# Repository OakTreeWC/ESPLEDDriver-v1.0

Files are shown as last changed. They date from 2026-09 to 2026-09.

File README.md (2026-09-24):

# ESPLEDDriver-v1.0 (In Progress)
ESPLEDDriver is an ESP Powered LED Driver Board for both Addressable and Non-Addressable LEDS. It features a ESP32-WROOM, with either a built in antenna or u.fl port, as well as 4 mosfet channels for powering monochrome and multicolor leds. 
All GPIO pins are exposed directly to the IO headers on the right side, and all power/led related IO can be found on the left side via the screw terminals.
Components have been sized accordingly to support 5-30V input, and up to 5 amps of current draw.



## Firmware
Due to the PD complexity of adding a USBC port to this project, I refrained from adding one. However, that does mean that programming the board requires using a USB to UART adapter.

In terms of firmware to be run on this, I will be using WLED, but ESPHome or any other ESP based software can be used to control it as well.

## Usage
This can be used in multiple ways, but what I believe is the most interesting (and fun) way to do it is to just integrate it with [Home Assistant](https://www.home-assistant.io/). If you really wanted to though, you could just use the Web Interface of WLED, or make your own firmware with its own API or something. The possibilities are literally endless, which is what makes the ESP platform so great.

## I/O
|Pin Number|Function|
|---|---|
|0|Addressable LED Data Line|
|4|Non-Addressable LED Channel 1/Red|
|5|Non-Addressable LED Channel 2/Green|
|6|Non-Addressable LED Channel 3/Blue|
|7|Non-Addressable LED Channel 4/White|

All other non-strapping pins are just free, so one may use them for any other purpose.

## Example Wiring Diagrams




## PCB



## Bill Of Materials
|Item |Description |Qty.|Unit Price (USD)|Total Price  (USD)|URL |Running Total (USD incl. tax)|
|---|---|----|---|---|---|---|
|ESP32-C3-WROOM-02U |ESP32 RF TXRX MOD BLUETOOTH U.FL SMD |1 |$3.71 |$3.71 |https://www.digikey.com/en/products/detail/espressif-systems/ESP32-C3-WROOM-02U-N4/15222540 |$3.71 |
|277-1580-ND |5POS Terminal Block, Side Entry, 5mm |1 |$1.28 |$1.28 |https://www.digikey.com/en/products/detail/phoenix-contact/1935190/568617 |$4.99 |
|277-1578-ND |3POS Terminal Block, Side Entry, 5mm |1 |$0.72 |$0.72 |https://www.digikey.com/en/products/detail/phoenix-contact/1935174/568615 |$5.71 |
|277-1667-ND |2POS Terminal Block, Side Entry, 5mm |1 |$0.53 |$0.53 |https://www.digikey.com/en/products/detail/phoenix-contact/1935161/568614 |$6.24 |
|IRLR2705PBFCT-ND |MOSFET N-CH 55V 28A DPAK |10  |$0.58 |$5.76 |https://www.digikey.com/en/products/detail/infineon-technologies/IRLR2705TRPBF/812649 |$12.00 |
|776-MAF95310-ND |185mm UFL Antenna |1 |$1.13 |$1.13 |https://www.digikey.com/en/products/detail/ezurio/MAF95310/5876486 |$13.13 |
|311-330HRCT-ND |RES 330 OHM 1% 1/10W 0603 |10  |$0.025 |$0.25 |https://www.digikey.com/en/products/detail/yageo/RC0603FR-07330RL/727162 |$13.38 |
|RNCP0603FTD10K0CT-ND |RES 10K OHM 1% 1/8W 0603 |10  |$0.01 |$0.12 |https://www.digikey.com/en/products/detail/stackpole-electronics-inc/RNCP0603FTD10K0/2240139 |$13.50 |
|5272-XL1509-3.3-EVCT-ND |XL1509 IC REG BUCK 3.3V 3A 8SOP |1 |$0.93 |$0.93 |https://www.digikey.com/en/products/detail/evvo/XL1509-3-3-EV/24370104 |$14.43 |
|4878-SK34SMA-3GCT-ND |DIODE SCHOTTKY 40V 3A SMA |1 |$0.35 |$0.35 |https://www.digikey.com/en/products/detail/diotec-semiconductor/SK34SMA-3G/13155211 |$14.78 |
|P16479CT-ND |CAP ALUM POLY 180UF 20% 16V SMD |1 |$1.55 |$1.55 |https://www.digikey.com/en/products/detail/panasonic-industry/16SVPF180M/4204811 |$16.33 |
|1276-1860-1-ND |CAP CER 1UF 50V X5R 0603 |10  |$0.08 |$0.80 |https://www.digikey.com/en/products/detail/samsung-electro-mechanics/CL10A105KB8NNNC/3887518 |$17.13 |
|36-3568-ND |FUSE HOLDER BLADE 500V 30A PCB |1 |$1.31 |$1.31 |https://www.digikey.com/en/products/detail/keystone-electronics/3568/2137306 |$18.44 |
|493-1111-ND |CAP ALUM 1000UF 20% 50V RADIAL |1 |$1.30 |$1.30 |https://www.digikey.com/en/products/detail/nichicon/UVR1H102MHD/588852 |$19.74 |
|SMBJ30ALFCT-ND |TVS DIODE 30VWM 48.4VC DO214AA |1 |$0.50 |$0.50 |https://www.digikey.com/en/products/detail/littelfuse-inc/SMBJ30A/286004 |$20.24 |
|SRR1210A-680MCT-ND |FIXED IND 68UH 3A 102 MOHM SMD |1 |$1.47 |$1.47 |https://www.digikey.com/en/products/detail/bourns-inc/SRR1210A-680M/5031009 |$21.71 |
|399-A768MS107M1HLAE024CT-ND|CAP ALUM POLY 100UF 20% 50V SMD |1 |$1.22 |$1.22 |https://www.digikey.com/en/products/detail/kemet/A768MS107M1HLAE024/12704540 |$22.93 |
|Female IO Headers |20PCS Single Row Straight Female Pin Socket Pin Header Connector Pin Strip 2.54mm Spacing for PCB Board Shield|1 |$5.99 |$5.99 |https://www.amazon.com/Ferwooh-Single-Straight-Connector-Spacing/dp/B0CZ6X313F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|$28.92 |
|450-1650-ND |SWITCH TACTILE SPST-NO 0.05A 24V |2 |$0.13 |$0.26 |https://www.digikey.com/en/products/detail/te-connectivity-alcoswitch-switches/1825910-6/1632536 |$29.18 |
|F989-ND |FUSE AUTOMOTIVE 5A 32VDC BLADE |2 |$0.39 |$0.78 |https://www.digikey.com/en/products/detail/littelfuse-inc/0297005-WXNV/146583 |$29.96 |
|Digikey Shipping | |1 |$4.99 |$4.99 | |$34.95 |
|Digikey Tariffs | |1 |$4.71 |$4.71 | |$39.66 |
|PCB |From JLCPCB |1 |$4.00 |$4.00 | |$43.66 |
|JLC Shipping | |1 |$6.77 |$6.77 | |$50.43 |
|Digikey TAX | |1 |$2.80 |$2.80 | |$53.23 |
|Amazon TAX | |1 |$0.63 |$0.63 | |$53.86 |

## AI Usage Declaration
AI was used in the making of this project, in component research, schematic/pcb verification, general sanity checks, as well as some copilot commit notes (for readme)

## Gallery




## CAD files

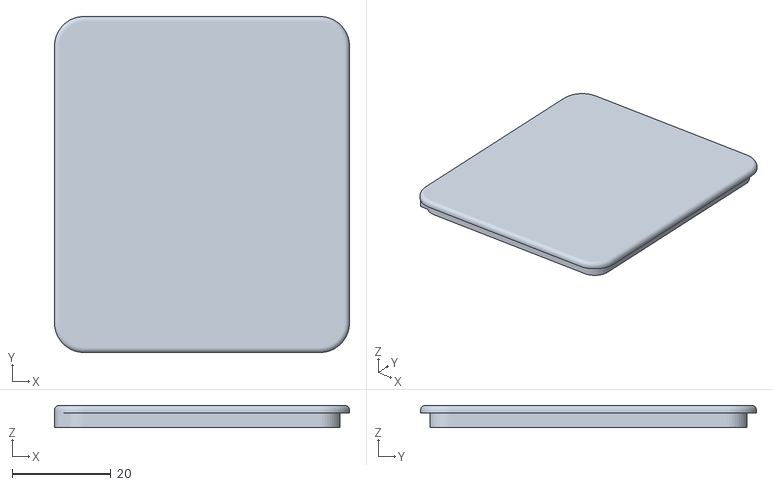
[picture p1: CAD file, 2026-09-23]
CAD/Upper Case.stl
59.6 x 67.9 x 4.50

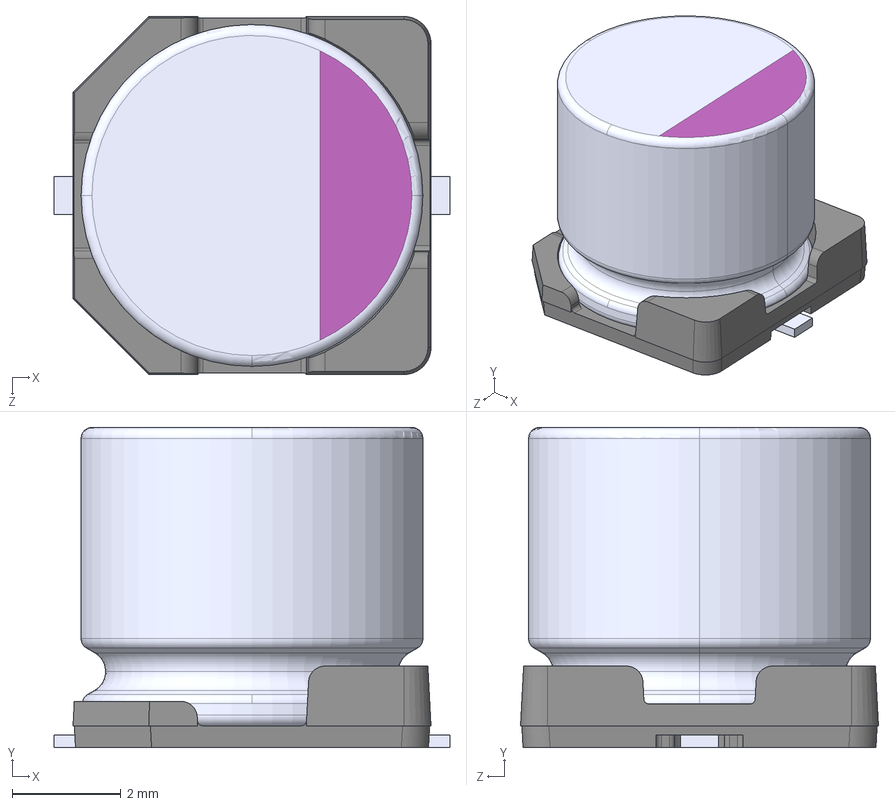
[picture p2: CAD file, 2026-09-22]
PCB/resources/16SVPF180M/16SVPF180M.step
7.30 x 5.90 x 6.60 mm

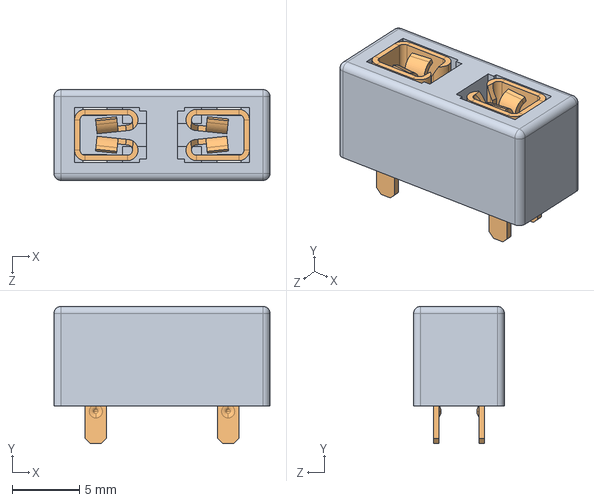
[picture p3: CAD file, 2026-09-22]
PCB/resources/3568/3568.step
16.0 x 10.2 x 6.73 mm
F3568-1
3557_rev.C x 2

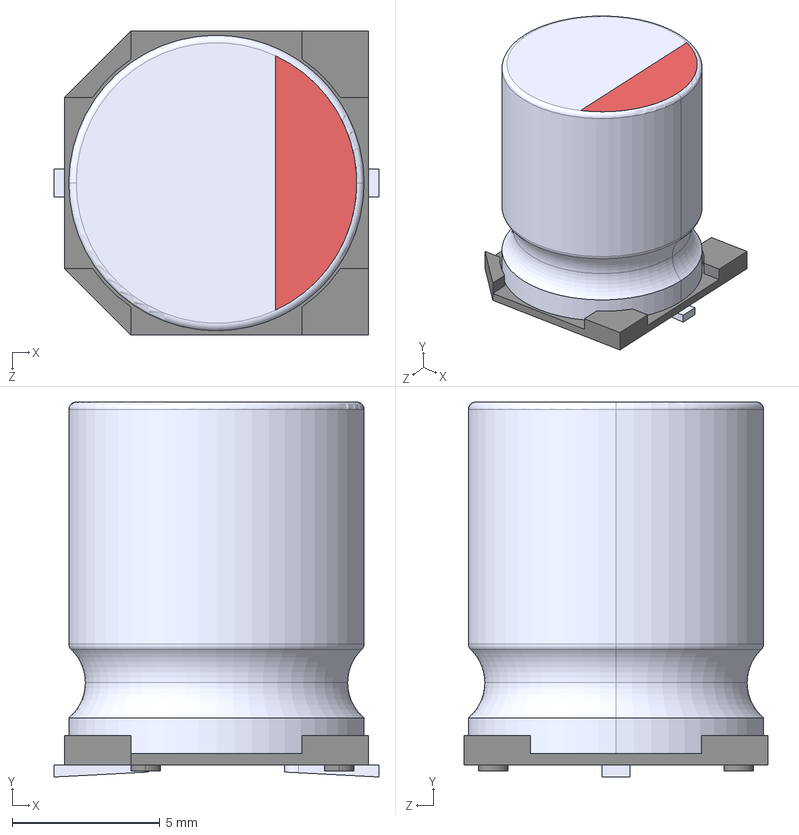
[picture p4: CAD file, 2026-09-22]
PCB/resources/A768MS107M1HLAE024/A768MS107M1HLAE024.step
11.0 x 12.7 x 10.3 mm

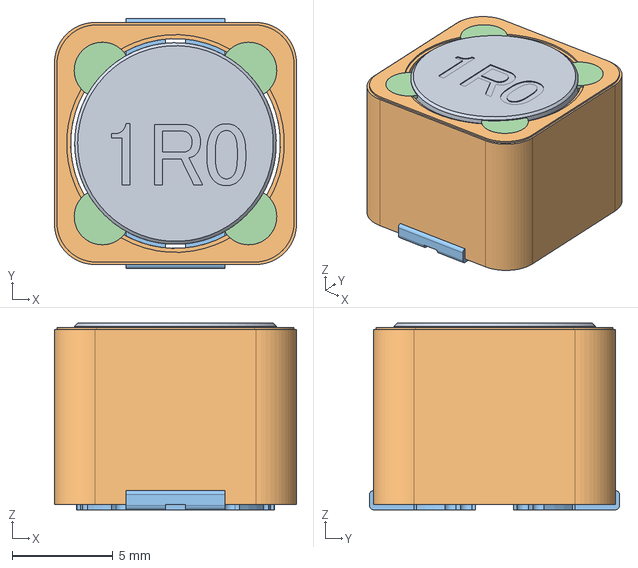
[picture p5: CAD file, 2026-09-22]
PCB/resources/SRR1210A.STP
12.0 x 12.4 x 9.25 mm

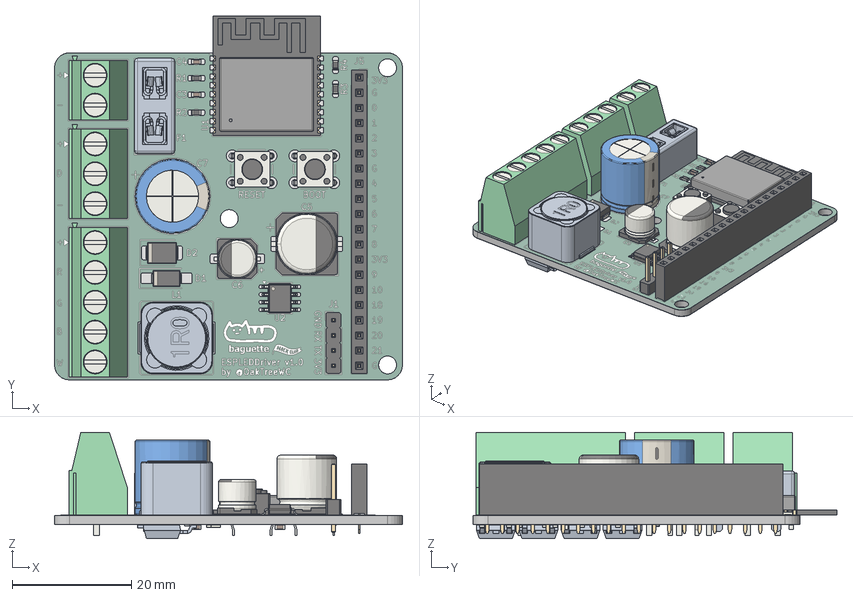
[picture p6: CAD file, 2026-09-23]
CAD/PCB.step
58.3 x 60.9 x 17.8 mm
PinSocket_1x20_P2.54mm_Vertical
CP_Radial_D12.5mm_P5.00mm
SRR1210A
D_SMB
ESP32-C3-WROOM-02
R_0603_1608Metric x 12
F3568-1
3557_rev.C x 2
SOIC-8_3.9x4.9mm_P1.27mm
CP_Elec_10x10
D_SMA
CP_Elec_6.3x5.9
TerminalBlock_Phoenix_MKDS-1,5-5_1x05_P5.00mm_Horizontal
TerminalBlock_Phoenix_MKDS-1,5-3_1x03_P5.00mm_Horizontal
C_0603_1608Metric x 4
SW_PUSH_6mm x 2
PinHeader_1x04_P2.54mm_Vertical
TerminalBlock_Phoenix_MKDS-1,5-2_1x02_P5.00mm_Horizontal
ESPLEDDriver 1.26.1 x 4
ESPLEDDriver_copper
ESPLEDDriver_pad
ESPLEDDriver_via
ESPLEDDriver_silkscreen x 2
ESPLEDDriver_soldermask x 2
ESPLEDDriver_PCB

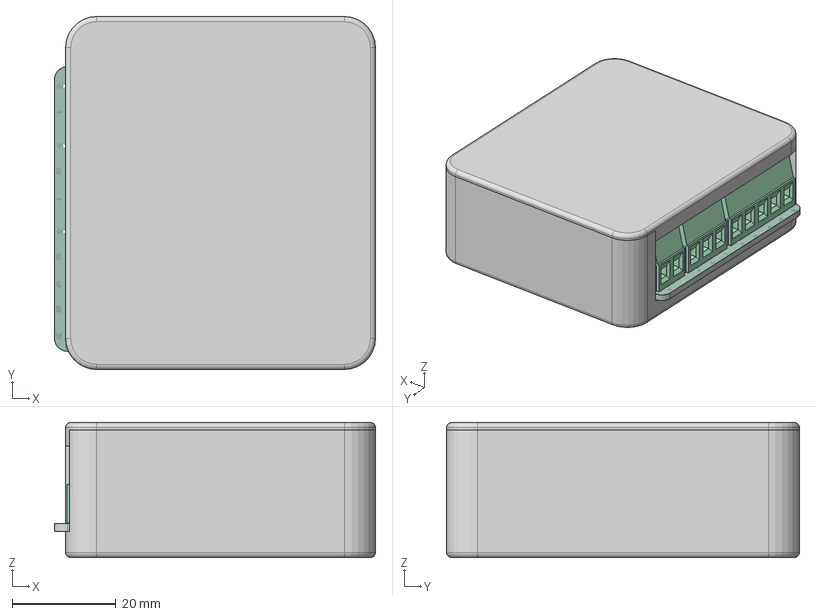
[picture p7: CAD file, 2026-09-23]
CAD/ESPLEDDriver.step
61.8 x 67.9 x 26.0 mm
PinSocket_1x20_P2.54mm_Vertical
CP_Radial_D12.5mm_P5.00mm
SRR1210A
D_SMB
ESP32-C3-WROOM-02
R_0603_1608Metric x 12
F3568-1
3557_rev.C x 2
SOIC-8_3.9x4.9mm_P1.27mm
CP_Elec_10x10
D_SMA
CP_Elec_6.3x5.9
TerminalBlock_Phoenix_MKDS-1,5-5_1x05_P5.00mm_Horizontal
TerminalBlock_Phoenix_MKDS-1,5-3_1x03_P5.00mm_Horizontal
C_0603_1608Metric x 4
SW_PUSH_6mm x 2
PinHeader_1x04_P2.54mm_Vertical
TerminalBlock_Phoenix_MKDS-1,5-2_1x02_P5.00mm_Horizontal
ESPLEDDriver 1.26.1 x 4
ESPLEDDriver_copper
ESPLEDDriver_pad
ESPLEDDriver_via
ESPLEDDriver_silkscreen
ESPLEDDriver_silkscreen_1
ESPLEDDriver_soldermask
ESPLEDDriver_soldermask_1
ESPLEDDriver_PCB

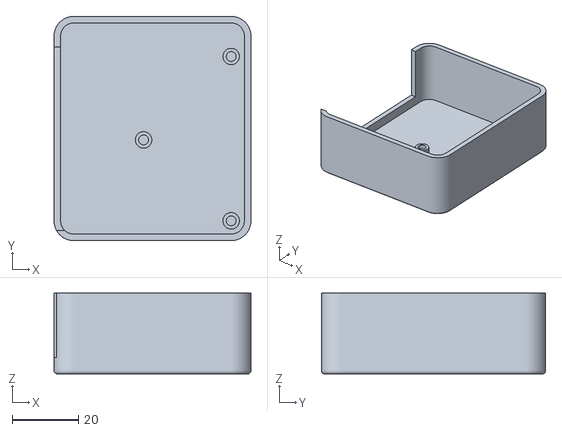
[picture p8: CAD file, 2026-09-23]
CAD/Lower Case.stl
59.6 x 67.9 x 24.5

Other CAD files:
CAD/ESPLEDDriver.f3d

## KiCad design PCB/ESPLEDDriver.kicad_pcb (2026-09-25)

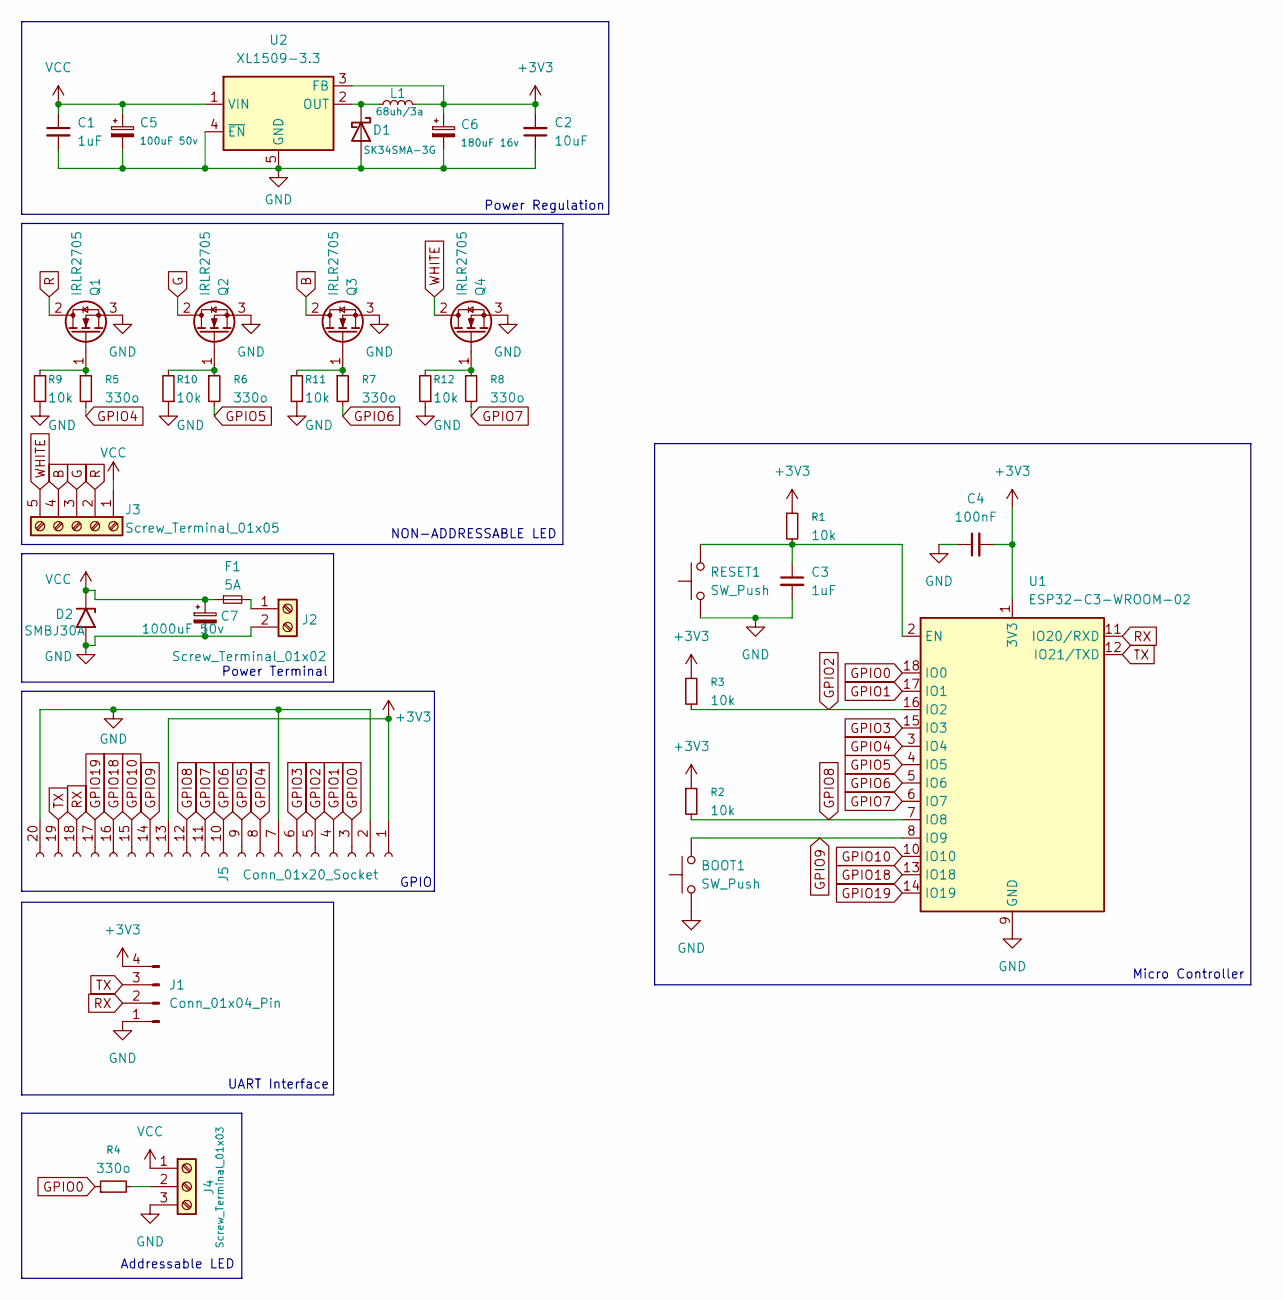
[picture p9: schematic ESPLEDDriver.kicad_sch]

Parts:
BOOT1: SW_Push; SW_PUSH_6mm
C1, C3: 1uF; C_0603_1608Metric_Pad1.08x0.95mm_HandSolder
C2: 10uF; C_0603_1608Metric_Pad1.08x0.95mm_HandSolder
C4: 100nF; C_0603_1608Metric_Pad1.08x0.95mm_HandSolder
C5: 100uF 50v; CP_Elec_10x10
C6: 180uF 16v; CP_Elec_6.3x5.9
C7: 1000uF 50v; CP_Radial_D12.5mm_P5.00mm
D1: SK34SMA-3G; D_SMA_Handsoldering
D2: SMBJ30A; D_SMB
F1: 5A; FUSE_3568
J1: Conn_01x04_Pin; PinHeader_1x04_P2.54mm_Vertical
J2: Screw_Terminal_01x02; TerminalBlock_Phoenix_PT-1,5-2-5.0-H_1x02_P5.00mm_Horizontal
J3: Screw_Terminal_01x05; TerminalBlock_Phoenix_PT-1,5-5-5.0-H_1x05_P5.00mm_Horizontal
J4: Screw_Terminal_01x03; TerminalBlock_Phoenix_PT-1,5-3-5.0-H_1x03_P5.00mm_Horizontal
J5: Conn_01x20_Socket; PinSocket_1x20_P2.54mm_Vertical
L1: 68uh/3a; L_Bourns_SRR1210A
Q1, Q2, Q3, Q4: IRLR2705; TO-252-2
R1, R2, R3, R9, R10, R11, R12: 10k; R_0603_1608Metric_Pad0.98x0.95mm_HandSolder
R4, R5, R6, R7, R8: 330o; R_0603_1608Metric_Pad0.98x0.95mm_HandSolder
RESET1: SW_Push; SW_PUSH_6mm
U1: ESP32-C3-WROOM-02
U2: XL1509-3.3; SOIC-8_3.9x4.9mm_P1.27mm

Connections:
+3V3: C2.2, C4.2, C6.1, J1.4, J5.1, J5.13, L1.2, R1.1, R2.1, R3.2, U1.1 (3V3), U2.3 (FB)
B: J3.4, Q3.2 (D)
G: J3.3, Q2.2 (D)
GND: BOOT1.1, C1.2, C2.1, C3.2, C4.1, C5.2, C6.2, C7.2, D1.2 (A), D2.2 (A2), J1.1, J2.2, J4.3, J5.2, J5.7, J5.20, Q1.3 (S), Q2.3 (S), Q3.3 (S), Q4.3 (S), R9.1, R10.1, R11.1, R12.1, RESET1.1, U1.9 (GND), U1.19 (GND), U2.4 (~EN), U2.5 (GND), U2.6 (GND), U2.7 (GND), U2.8 (GND)
GPIO0: J5.3, R4.1, U1.18 (IO0)
GPIO1: J5.4, U1.17 (IO1)
GPIO2: J5.5, R3.1, U1.16 (IO2)
GPIO3: J5.6, U1.15 (IO3)
GPIO4: J5.8, R5.2, U1.3 (IO4)
GPIO5: J5.9, R6.2, U1.4 (IO5)
GPIO6: J5.10, R7.2, U1.5 (IO6)
GPIO7: J5.11, R8.2, U1.6 (IO7)
GPIO8: J5.12, R2.2, U1.7 (IO8)
GPIO9: BOOT1.2, J5.14, U1.8 (IO9)
GPIO10: J5.15, U1.10 (IO10)
GPIO18: J5.16, U1.13 (IO18)
GPIO19: J5.17, U1.14 (IO19)
unnamed: D1.1 (K), L1.1, U2.2 (OUT)
unnamed: F1.2, F1.4, J2.1
unnamed: J4.2, R4.2
unnamed: Q1.1 (G), R5.1, R9.2
unnamed: Q2.1 (G), R6.1, R10.2
unnamed: Q3.1 (G), R7.1, R11.2
unnamed: Q4.1 (G), R8.1, R12.2
unnamed: C3.1, R1.2, RESET1.2, U1.2 (EN)
R: J3.2, Q1.2 (D)
RX: J1.2, J5.18, U1.11 (IO20/RXD)
TX: J1.3, J5.19, U1.12 (IO21/TXD)
VCC: C1.1, C5.1, C7.1, D2.1 (A1), F1.1, F1.3, J3.1, J4.1, U2.1 (VIN)
WHITE: J3.5, Q4.2 (D)

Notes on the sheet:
NON-ADDRESSABLE LED
UART Interface
GPIO
Power Regulation
Micro Controller
Addressable LED
Power Terminal

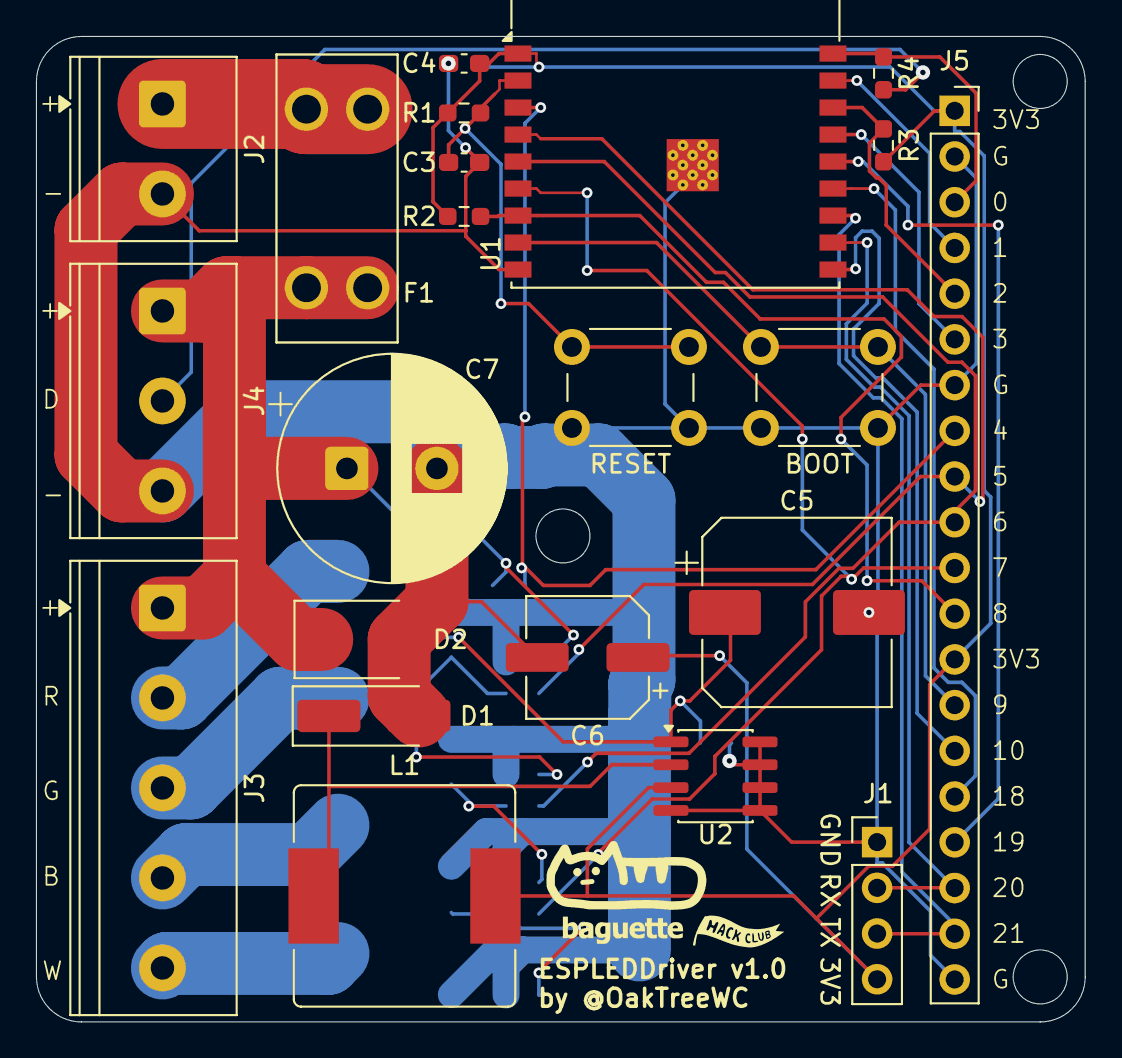
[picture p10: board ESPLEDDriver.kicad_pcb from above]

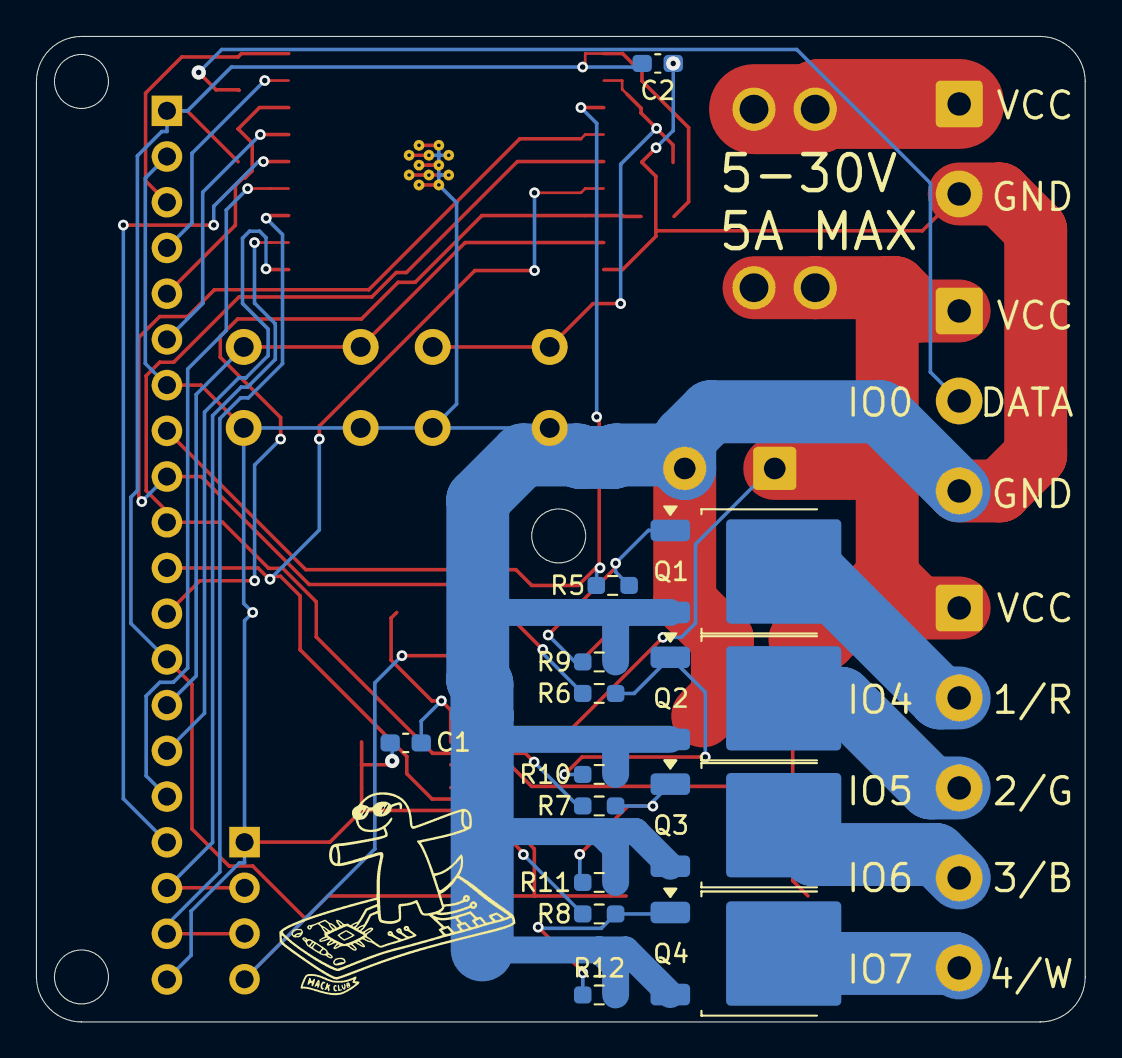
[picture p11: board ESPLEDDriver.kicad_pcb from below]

Board: 2 copper layers, 58.3 x 54.8 mm, 36 parts (14 on the bottom side), 30 nets.

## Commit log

2026-09-22 KiCad Init
    [16SVPF180M.step, 3568.step, A768MS107M1HLAE024.step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]
2026-09-22 Gerbers, PCB final touches
    [ESPLEDDriver-B_Cu.gbr, ESPLEDDriver-B_Mask.gbr, ESPLEDDriver-B_Paste.gbr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]
2026-09-22 Enhance README with detailed project information
    Expanded the project description, added firmware and usage sections, detailed I/O pin functions, and included a Bill of Materials section.
2026-09-23 Update README with PCB badge and AI usage declaration
    Added PCB link, updated firmware usage description, and included AI usage declaration.
2026-09-23 created case, finalized pcb (for realsies this time)
    [16SVPF180M.step, 3568.step, A768MS107M1HLAE024.step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]
2026-09-23 created case, finalized pcb (for realsies this time)\
    [BOM.csv]
2026-09-23 Update README with Bill of Materials and AI Declaration
    Expanded the Bill of Materials section with detailed item descriptions, quantities, unit prices, and total prices for each component. Added an AI Usage Declaration section to acknowledge the use of A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
2026-09-23 Add example schematics to README
    Added example schematics images to the README.
2026-09-23 Created Example Wiring Schematic in KiCad
    [Example Wiring Schematic.kicad_sch]
2026-09-24 Rename Example Schematics to Example Wiring Diagrams
    Updated section titles and added PCB images.
2026-09-24 Updated BOM with final numbers
    [BOM.csv]
2026-09-24 Revise Bill Of Materials with updated pricing and taxes
    Updated Bill Of Materials with new item prices and links, and added tax details.
2026-09-25 slightly modified schematic and pcb due to incorrect screw terminal footprint
    [ESPLEDDriver.kicad_pcb, ESPLEDDriver.kicad_sch]
